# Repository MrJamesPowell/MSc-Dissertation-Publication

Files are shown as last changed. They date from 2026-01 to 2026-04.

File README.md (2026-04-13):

# MSc-Dissertation-Publication<br>
Repository of code used for the authors dissertation for a Master of Science in Mechanical Engineering, titled "Design, Manufacture and Evaluation of a Heated Blanket for Treatment of Hypothermia".<br>
This repository also contains code used for the additional work for publication of the dissertation material.<br>

---

## Component list<br>
### Resistors<br>
R1 = 4.7K<br>
R2 = 1K<br>
R3 = 10K<br>
_Note: All resistors used were 1/8 W metal film_<br>
### Microcontroller<br>
Pro Micro purchased from [Amazon.co.uk](https://www.amazon.co.uk/s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)<br>
Code: [Heater-PID-controller](Heater-PID-controller.ino)<br>
### Transistor<br>
Q1 = MOSFET [IRL540N](https://www.mouser.co.uk/ProductDetail/Infineon-Technologies/IRL540NPBF?qs=9%252BKlkBgLFf0uZBCvyYsQoQ%3D%3D), Infineon Technologies AC<br>
### Connectors<br>
Wired connections: [2 pin terminal block](https://www.mouser.co.uk/ProductDetail/TE-Connectivity/282837-2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)<br>
Microcontroler interface: [12 pin stackable header](https://www.mouser.co.uk/ProductDetail/SparkFun/PRT-14322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)<br>
### PCB <br>
The PCB was manufactured using a single sided copper clad board and etched with the pattern in the [gerber file](Gerber_BottomLayer.GBL)<br>

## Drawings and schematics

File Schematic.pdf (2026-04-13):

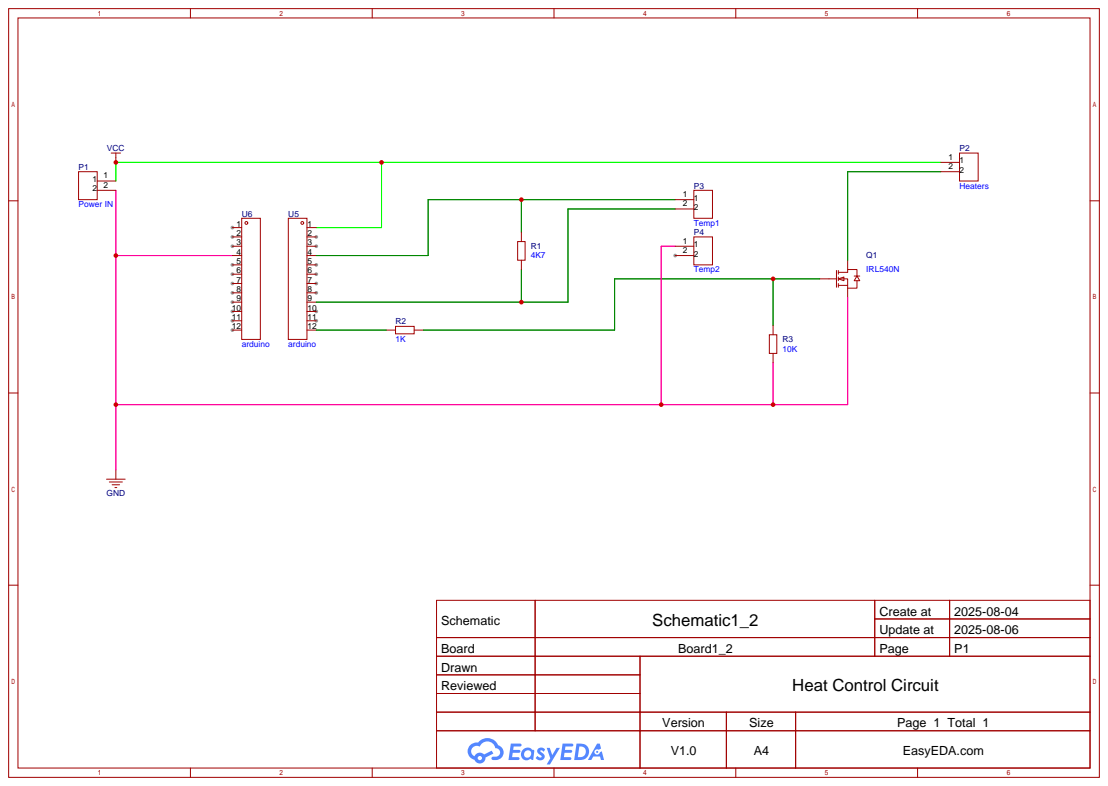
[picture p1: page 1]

Schematic | Schematic1_2 | Create at | 2025-08-04

Update at | 2025-08-06

Board | Board1_2 | Page | P1
Drawn | | Heat Control Circuit
Reviewed

Version | Size | Page 1 Total 1
V1.0 | A4 | EasyEDA.com

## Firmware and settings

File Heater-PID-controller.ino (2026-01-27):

#include <OneWire.h>
#include <DallasTemperature.h>
#include <PID_v2.h>


#define ONE_WIRE_BUS 15 //Data wire of temperature sensor
#define HEATER_PIN 10 //Mosfet gate
#define STATUS_LED_PIN 6 //Staus LED (external status led, not used in final circuit)

// debug term used for pritnitng things on the fly if theres a problem
bool debug = false; //For normal operation, set to flase. If true P, I and D values will be printed in the command window

// PID tuning parameters (these were chosen using Ziegler-Nichols open loop method)
double Kp = 50.89; // Proportional gain
double Ki = 3.4; //Integral gain (set to 0 for P controller)
double Kd = 114.25; //Derivative gain (set to 0 for P or PI controller)

double TargetTemp = 40.0; //target temperature 
double TempC; //measured temperature, not declared yet
double Output; //PWM output 

double myLastP ;
double myLastI ;
double myLastD ;


OneWire oneWire(ONE_WIRE_BUS); //Declare one wire temp sensor pin is 15
DallasTemperature sensors(&oneWire);



PID myPID(&TempC, &Output, &TargetTemp, Kp, Ki, Kd, DIRECT);

unsigned long lastRequest = 0;
unsigned long lastTempRequest = 0;
const unsigned long sampleIntervalMs = 1000; // sample every 1s
const unsigned long sampleTempIntervalMs = 1000; // sample every 1s


void setup() {

  Serial.begin(9600);
  sensors.begin();

  pinMode(HEATER_PIN, OUTPUT);
  digitalWrite(HEATER_PIN, LOW);
  digitalWrite(STATUS_LED_PIN, LOW);

  //Configure PID
  myPID.SetMode(AUTOMATIC); //Turn the PID on 
  myPID.SetOutputLimits(0,255); //maps to analogwrite
  myPID.SetSampleTime(sampleIntervalMs); // Sets the sample time to 1s

  //delay(1000);
  Serial.print("Temp,PWM");
  if (debug) {
  Serial.print(",Pterm,Iterm,Dterm");
  Serial.print('\n');
  }

}

void loop() {

  unsigned long now = millis();

  // if loop only activates if the sample interval has passed
  if (now - lastTempRequest >= sampleTempIntervalMs) { 
    lastTempRequest = now;

    // request temperature
    sensors.requestTemperatures(); 
    sensors.setWaitForConversion(false); // this sets the temperature sensor to non blocking so PWM and temp can run in parallel
    TempC = sensors.getTempCByIndex(0);
  }

  if (now - lastRequest >= sampleIntervalMs) { 
    lastRequest = now;

    if (TempC < 45) { // safety cutoff
      myPID.Compute(); // calculate a new output 
      myLastP = myPID.GetLastP();
      myLastI = myPID.GetLastI();
      myLastD = myPID.GetLastD();

    }
    else { // set power to zero if safety limit is exceeded
      Output = 0;
    }


    analogWrite(HEATER_PIN, (int)Output); //PWM signal to MOSFET
    analogWrite(STATUS_LED_PIN, (int)Output); //PWM signal to status LED

  
    Serial.print(TempC); //Serial print temperature in deg C
    Serial.print(','); //Comma used as deliminator 
   
    Serial.print((int)Output); //Serial print the PWM signal in command window
  

    if (debug) {
      Serial.print(',');
      Serial.print(myLastP);
      Serial.print(',');
      Serial.print(myLastI);
      Serial.print(',');
      Serial.print(myLastD);
    }
  
    Serial.print('\n');
  
  }

}

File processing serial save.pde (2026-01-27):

import processing.serial.*; 

Serial myPort;
PrintWriter output;
int startTime;

void setup() {
  // List all available ports
  printArray(Serial.list());

  // Pick the right port (change [0] if needed)
  myPort = new Serial(this, Serial.list()[7], 9600);

  // Create timestamped filename
  String filename = year() + "-" + nf(month(),2) + "-" + nf(day(),2) +
                    "_" + nf(hour(),2) + "-" + nf(minute(),2) + "-" + nf(second(),2) +
                    ".csv";
  output = createWriter(filename);

  // Record the start time
  startTime = millis();

  println("Saving to file: " + filename);
}

void draw() {
  if (myPort.available() > 0) {
    String data = myPort.readStringUntil('\n');
    if (data != null) {
      data = trim(data);

      // Time passed since start (in seconds, with decimals)
      float elapsed = (millis() - startTime) / 1000.0;

      // Save with elapsed time
      String line = nf(elapsed, 0, 3) + " , " + data; // 3 decimals
      println(line);
      output.println(line);
      output.flush();
    }
  }
}

void keyPressed() {
  output.close();
  exit();
}

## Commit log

2026-01-27 Create Heater PID controller
2026-01-27 Rename Heater PID controller to Heater PID controller.ino
2026-01-27 Update Heater PID controller.ino
2026-01-27 Update processing serial save.pde
    This code is used in "Processing" to save the timestamped serial data incoming from the Arduino
2026-04-13 Rename CC Schematic.pdf to Schematic.pdf
2026-04-13 Rename Heater PID controller.ino to Heater_PID_controller.ino
